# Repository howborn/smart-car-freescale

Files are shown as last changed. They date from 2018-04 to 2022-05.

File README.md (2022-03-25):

# [第九届飞思卡尔智能车](https://www.fanhaobai.com)

此为第九届飞思卡尔智能车摄像头组参赛作品，为了该作品我和团队泡了 1 年半的实验室。该作品我早已在 [智能车制作](http://www.znczz.com) 论坛开源过，现整理于 Github。

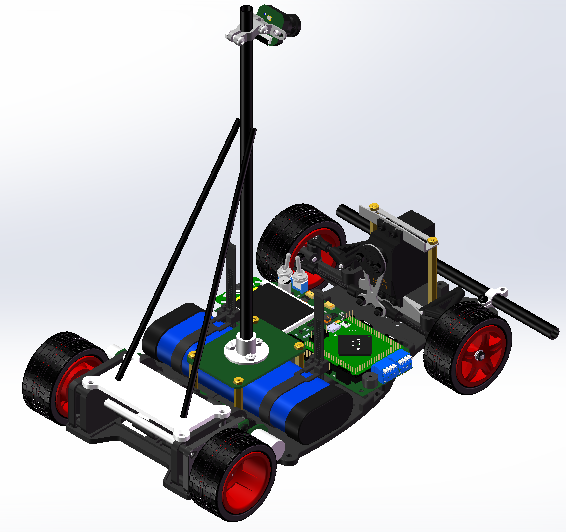
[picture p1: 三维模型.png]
预览图


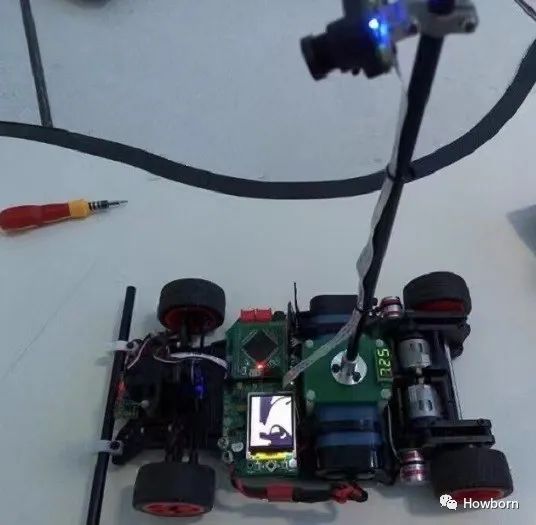
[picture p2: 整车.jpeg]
整车图


该作品系统架构为 K60 处理器 + MT9V034 CMOS 摄像头。

## [自动行驶原理](https://github.com/fan-haobai/smart-car-freescale/tree/master/4.Paper)

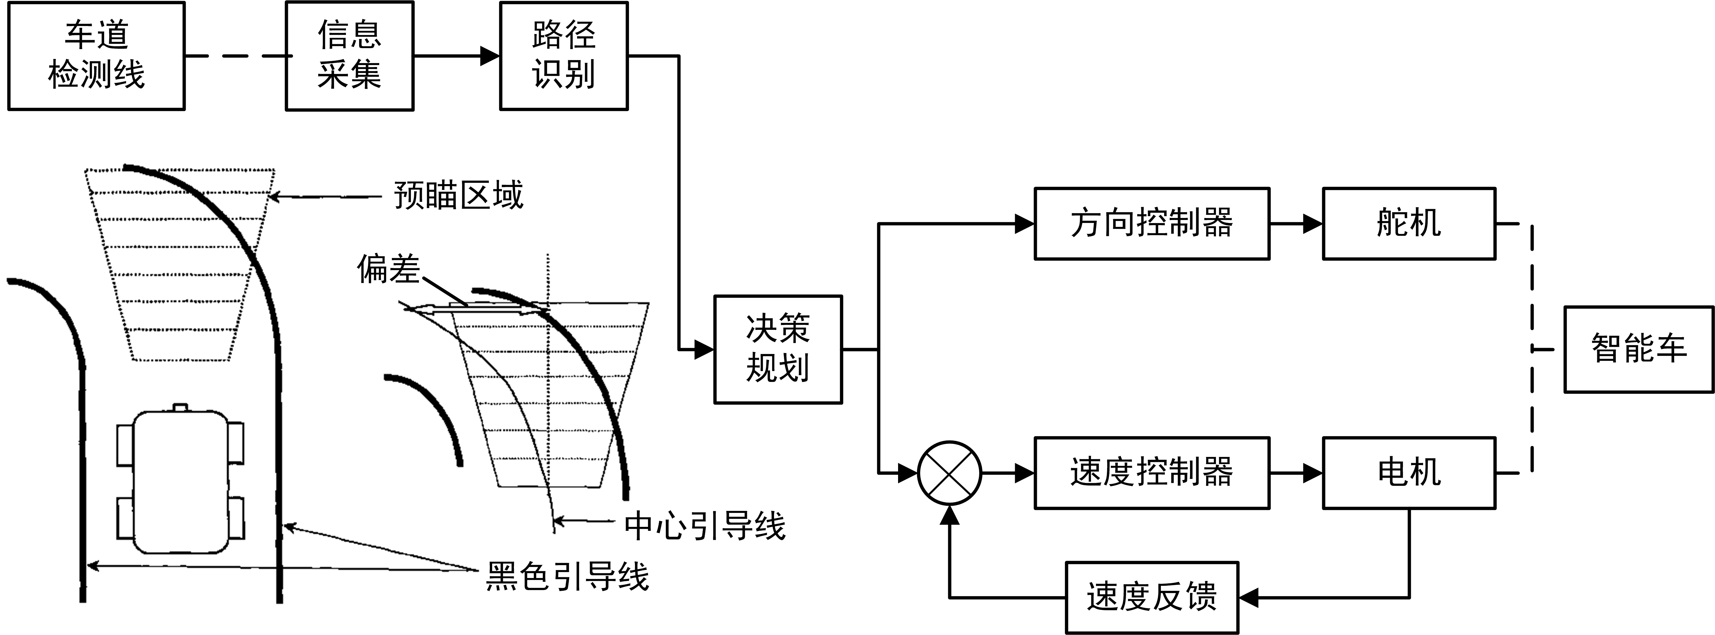
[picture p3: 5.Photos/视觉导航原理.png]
原理


整个系统通过图像识别技术感知赛道路况，进而使用 PID 算法控制智能车的速度和方向，实现智能车的自动导航功能。

## [三维建模](https://github.com/fan-haobai/smart-car-freescale/tree/master/1.3D)

使用 SolidWorks 软件对智能车进行建模分析。

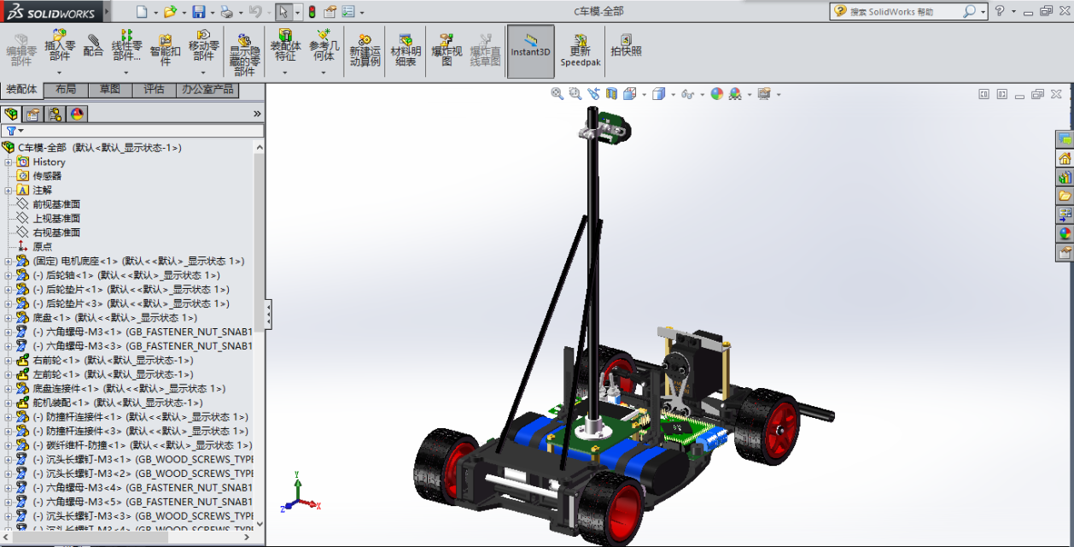
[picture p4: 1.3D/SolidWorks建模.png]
车架


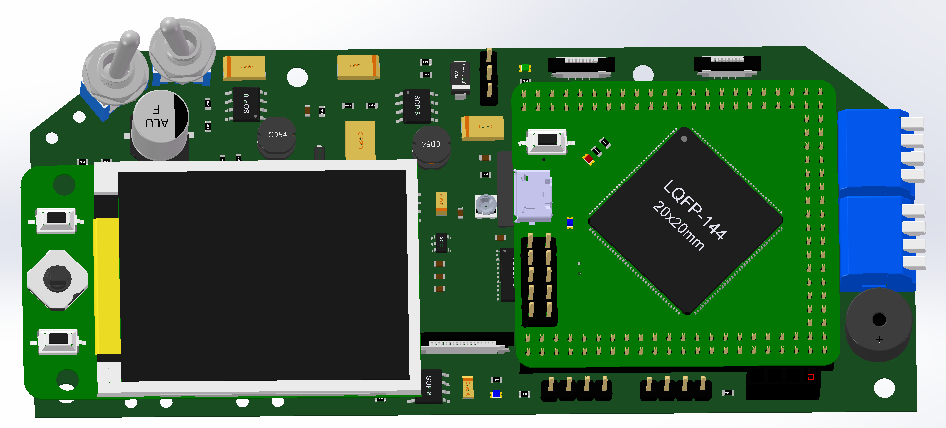
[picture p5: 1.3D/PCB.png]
PCB


## [硬件电路](https://github.com/fan-haobai/smart-car-freescale/blob/master/2.Hardware)

硬件电路主要分为4个子部分：

* [摄像头](https://github.com/fan-haobai/smart-car-freescale/blob/master/2.Hardware/摄像头.PDF)
* [K60 最小系统](https://github.com/fan-haobai/smart-car-freescale/blob/master/2.Hardware/K60最小系统.PDF)
* [可视化交互界面](https://github.com/fan-haobai/smart-car-freescale/blob/master/2.Hardware/1.8-TFT-128x160.PDF)
* [主板](https://github.com/fan-haobai/smart-car-freescale/blob/master/2.Hardware/主板__V1.0.PDF)

其中，部分电路原理图：

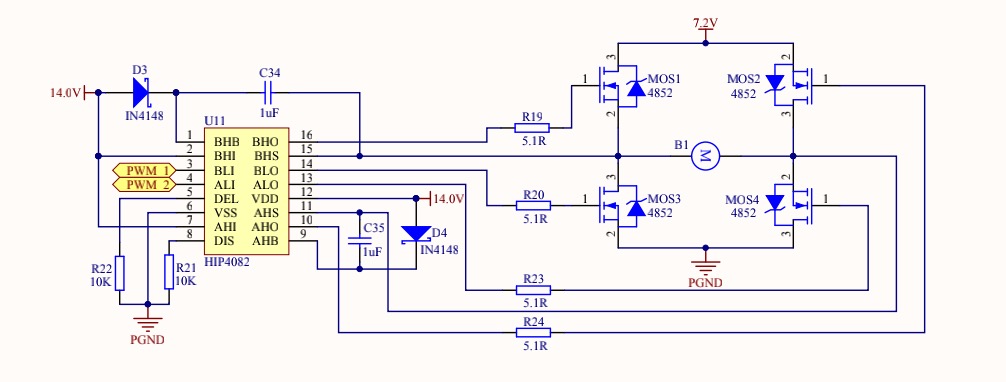
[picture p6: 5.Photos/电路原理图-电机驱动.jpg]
电机驱动


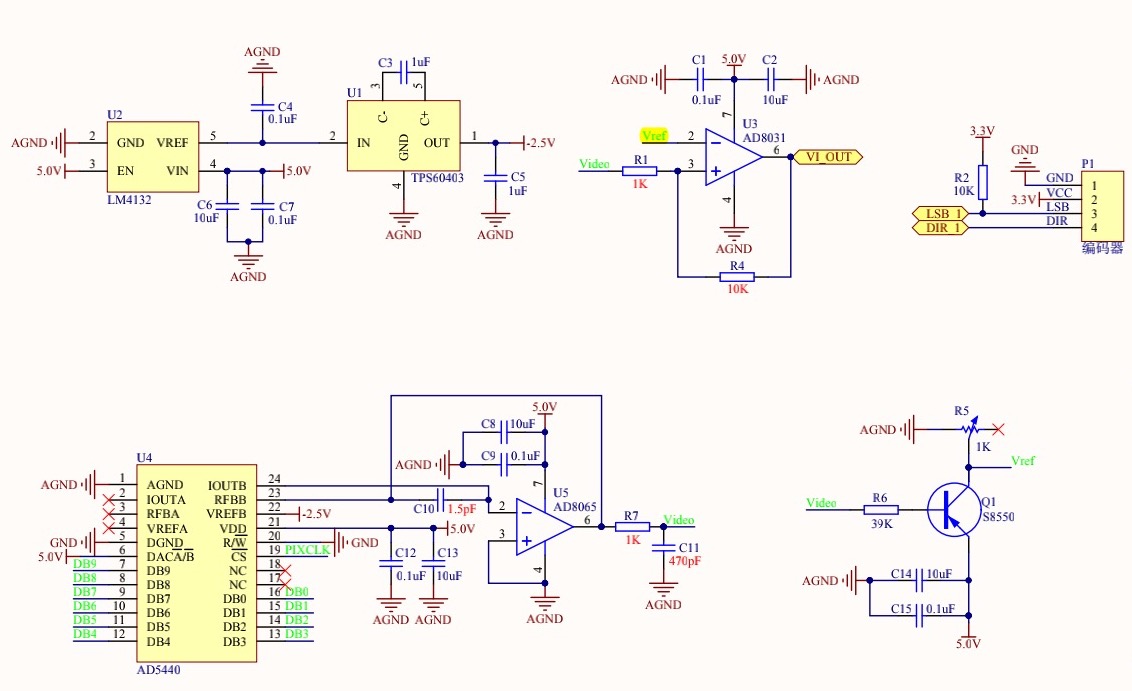
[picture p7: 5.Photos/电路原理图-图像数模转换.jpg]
图像数模转换


## [软件源码](https://github.com/fan-haobai/smart-car-freescale/blob/master/3.Software)

软件主要功能包括:

* [K60 初始化和调度](https://github.com/fan-haobai/smart-car-freescale/blob/master/3.Software/src/Init.c)
* [MT9V034 图像采集](https://github.com/fan-haobai/smart-car-freescale/blob/master/3.Software/src/MT9V034.c)
* [图像分析](https://github.com/fan-haobai/smart-car-freescale/blob/master/3.Software/src/Analyze.c)
* [Flash数据存储](https://github.com/fan-haobai/smart-car-freescale/blob/master/3.Software/src/Flash.c)
* [可视化界面（GUI）](https://github.com/fan-haobai/smart-car-freescale/blob/master/3.Software/src/Gui.c)
* [PID 自动控制](https://github.com/fan-haobai/smart-car-freescale/blob/master/3.Software/src/Control.c)

## [毕业论文](https://github.com/fan-haobai/smart-car-freescale/tree/master/4.Paper)

我的本科毕业设计就是基于该作品，并获得了《优秀毕业论文》称号。

## [相册](https://github.com/fan-haobai/smart-car-freescale/tree/master/5.Photos)

制作过程中所有的图片汇集。例如赛道识别图像：

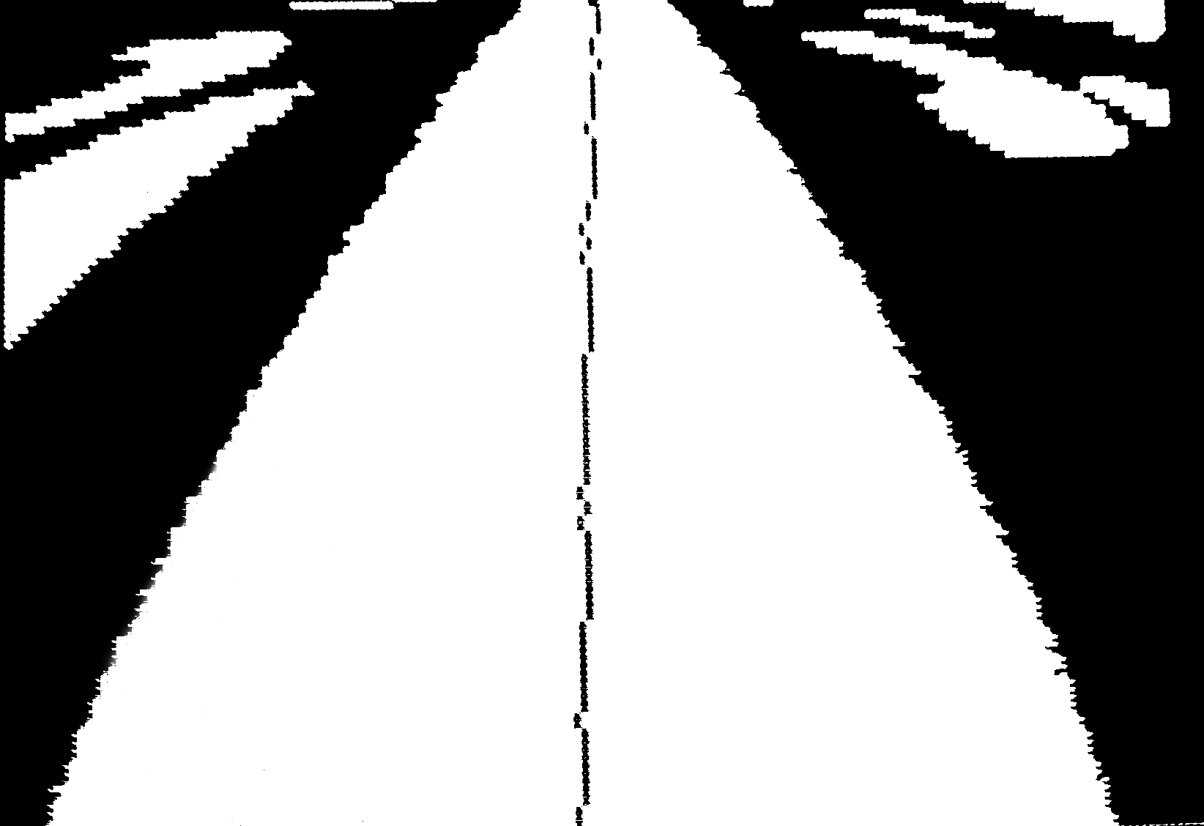
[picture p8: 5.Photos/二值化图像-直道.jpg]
二值化图像-直道


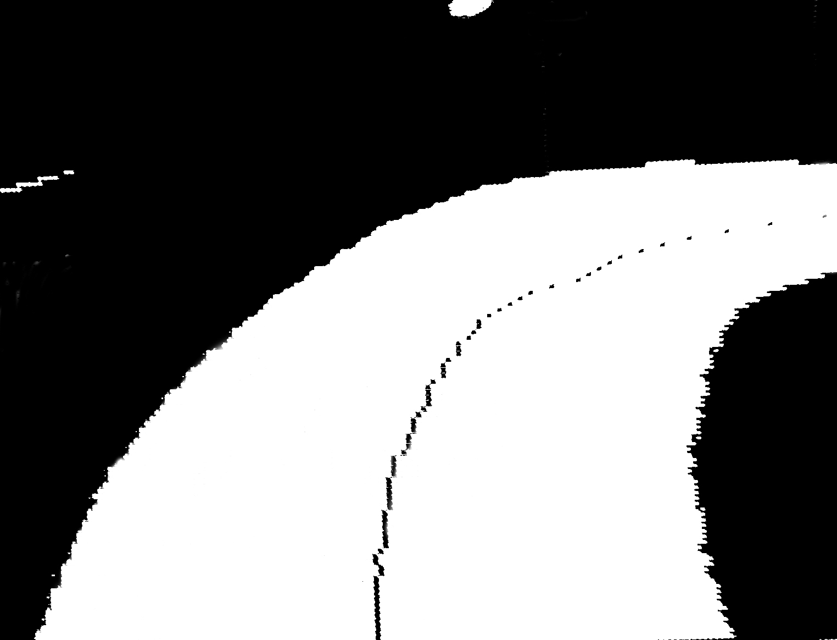
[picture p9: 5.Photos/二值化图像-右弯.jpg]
二值化图像-右弯


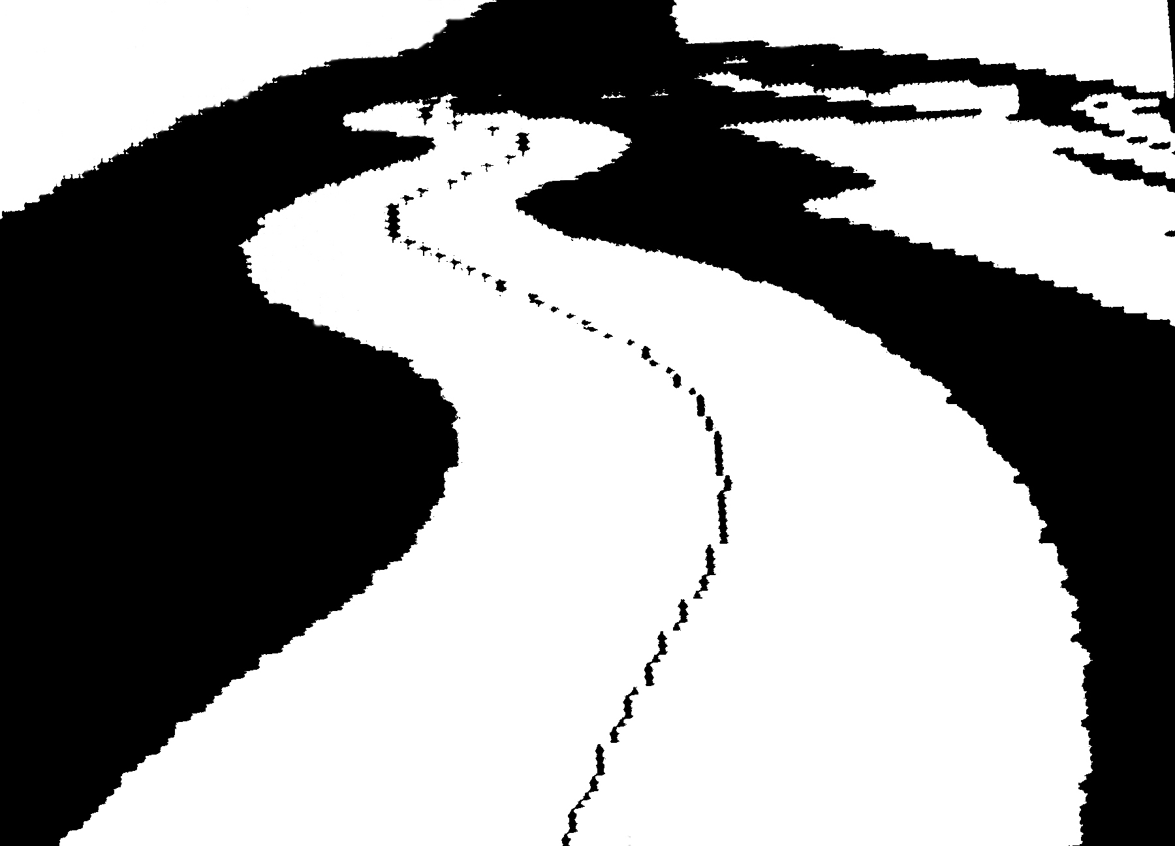
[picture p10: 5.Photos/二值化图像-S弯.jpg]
二值化图像-S弯


## 自动行驶视频

* [实验室调试视频](https://v.youku.com/v_show/id_XODE0NTg2NzY4.html)
* [校内赛](https://v.youku.com/v_show/id_XOTI0NzM1NDM2.html)
* [华北赛](https://v.youku.com/v_show/id_XODUxOTUyNjk2.html)

**最后要说的是，通过这次比赛，巩固了基础知识，也充实了大学生活。**

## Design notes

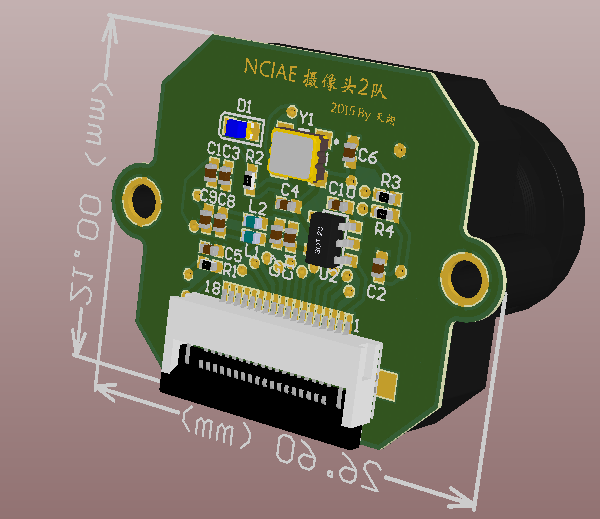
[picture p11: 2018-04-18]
2.Hardware/摄像头/3D.png

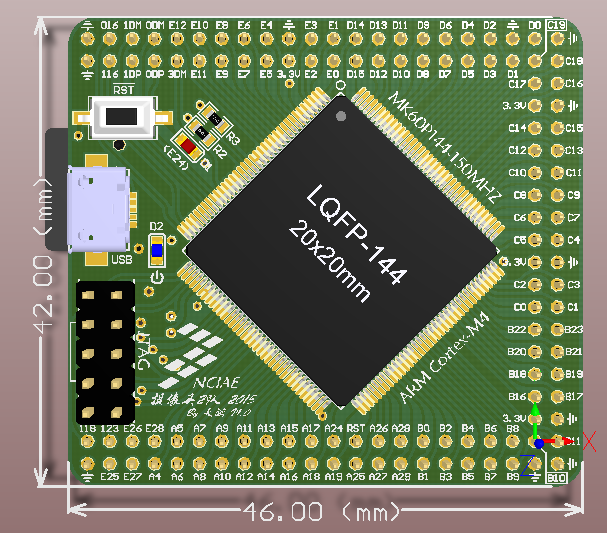
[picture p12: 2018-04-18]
2.Hardware/K60最小系统/3D.png

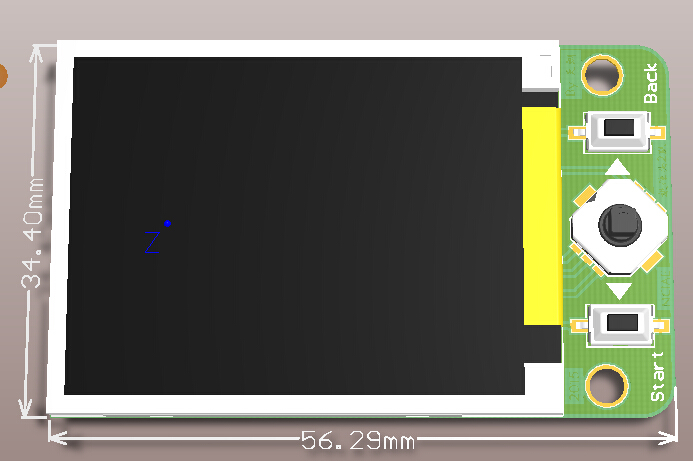
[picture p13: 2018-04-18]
2.Hardware/可视化交互界面/3D.jpg

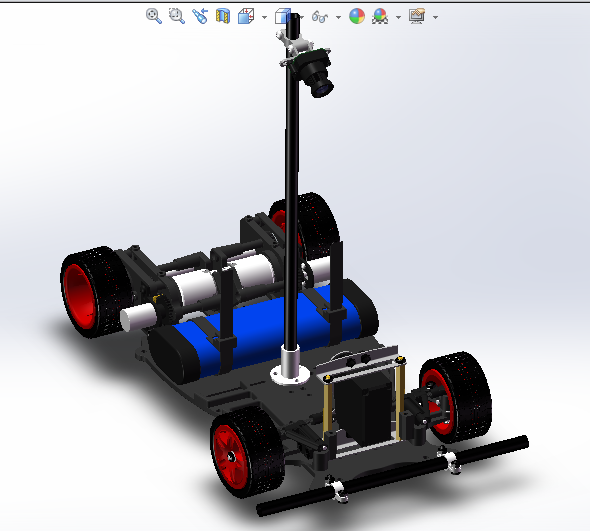
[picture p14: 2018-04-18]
1.3D/车架部分.png

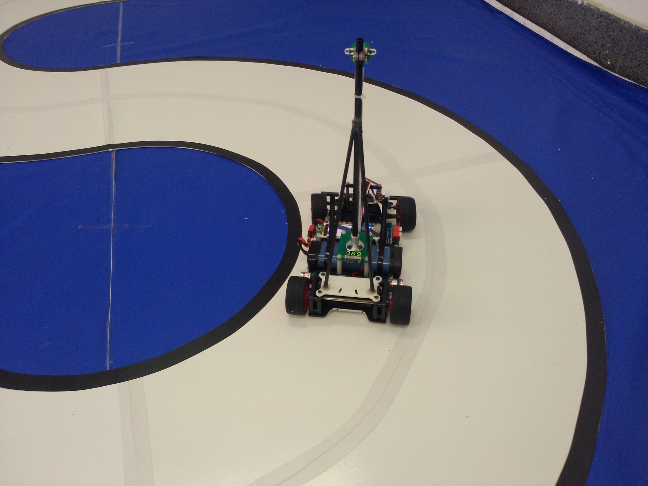
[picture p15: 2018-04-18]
5.Photos/整车-赛道.jpg

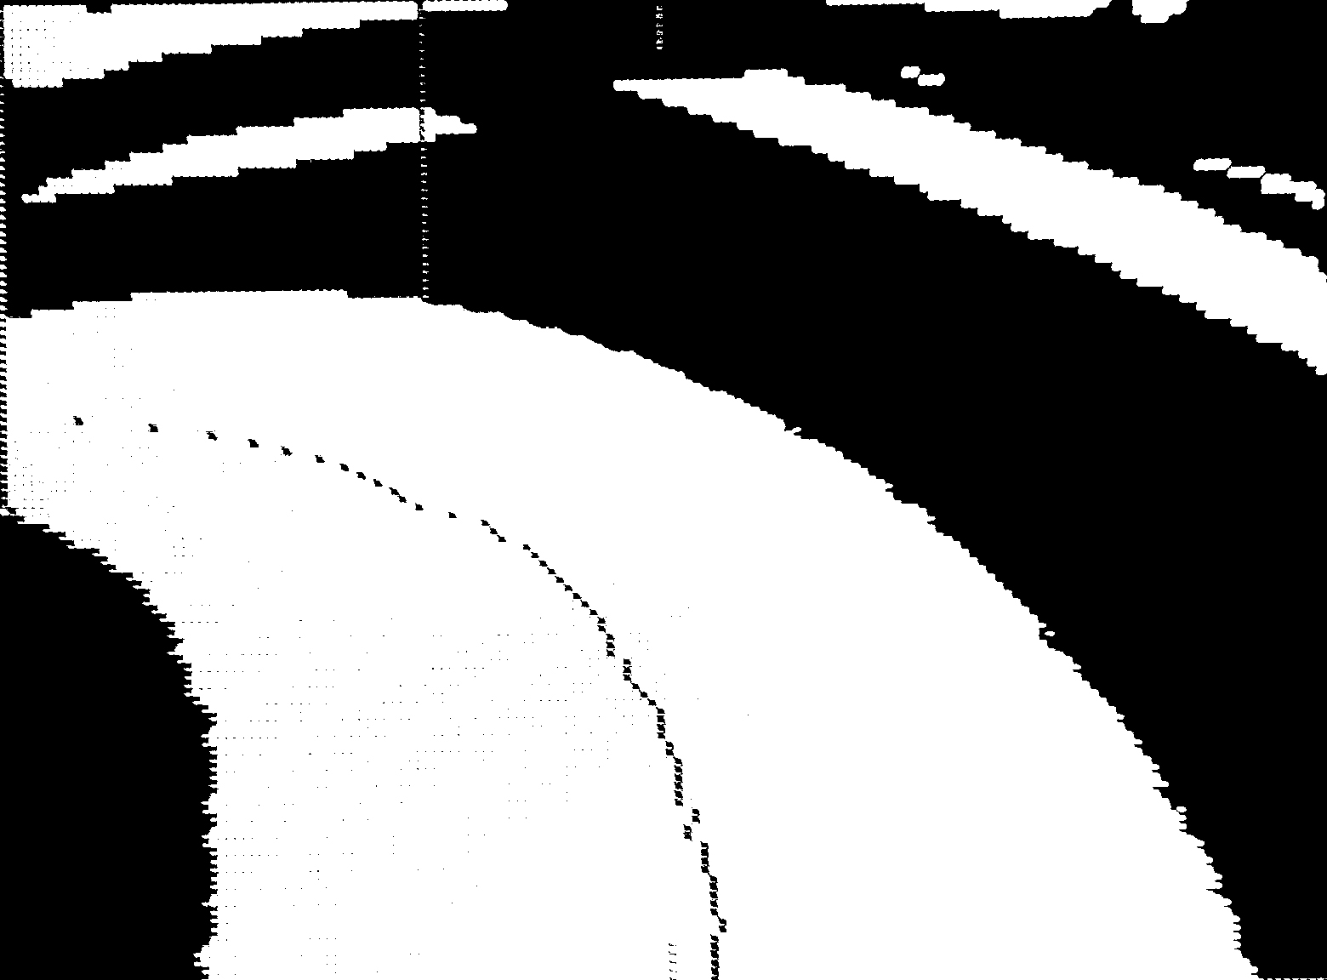
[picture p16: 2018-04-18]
5.Photos/二值化图像-左道.jpg

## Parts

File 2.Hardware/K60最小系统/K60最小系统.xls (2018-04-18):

Comment | Designator | Footprint | Quantity
0.01uF | C15 | CAP-0603 | 1
0.1uF | C1, C2, C7, C8, C9, C10, C11, C12, C13, C14, C16 | CAP-0603 | 11
0R | R8, R9 | RES-0603 | 2
100OHM@100MHZ | L1, L2 | Chip Inductor-0603_160808 | 2
10K | R1, R7 | RES-0603 | 2
10nF | C5 | CAP-0603 | 1
10uF | C17 | CASE-A_3216-18 | 1
1K | R4, R5 | RES-0603 | 2
1M | R6 | RES-0603 | 1
22pF | C3, C4 | CAP-0603 | 2
22R | R2, R3 | RES-0603 | 2
32.768k | Y1 | XTAL-XYL-SMD | 1
4.7uF | C6 | CAP-0603 | 1
4733 | D3, D4 | Diode-SMD-1206 | 2
500mA | F1 | Fuse-1206 | 1
50MHZ/3.3V | Y2 | XTAL-OSC-3225 | 1
CON-20X2 | CN1, CN2, CN3 | Pin-Header-2.00-Double-40 | 3
JTAG | CN4 | Pin-Header-2.54-Double-10 | 1
Key | RST | SW-PB-2 | 1
LED | D1 | LED-RED-0603 | 1
LED | D2 | LED-BLU-0603 | 1
ME6211-3.3 | U2 | SOT-23-5 | 1
Mini-USB-A | USB | Mini-USB(a)-SMD | 1
MK60FX512VLQ15 | U1 | LQFP-144-20x20mm | 1
SD | Micro SD | Micro-SD | 1

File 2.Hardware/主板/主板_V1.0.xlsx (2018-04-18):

Comment | Designator | Footprint | Quantity
Motor | B1, B2 | Header-5.0-SMD | 2
Battery | BT | Header-5.0-SMD | 1
0.1uF | C1, C4, C7, C9, C12, C15, C17, C23, C24, C26, C27, C28, C29, C38, C39 | CAP-0603 | 15
10uF | C2, C6, C8, C13, C14, C22, C25 | CAP-0603 | 7
1uF | C3, C5, C34, C35, C36, C37 | CAP-0603 | 6
1.5pF | C10 | CAP-0603 | 1
470pF | C11 | CAP-0603 | 1
100uF | C16, C18, C20 | CASE-C_6032-28 | 3
180pF | C19 | CAP-0603 | 1
100uF/25V | C21 | CASE-D_7343-31 | 1
10uF | C30, C31, C32 | CASE-A_3216-18 | 3
470uF | C33 | CAP-ALU-F_8.0x8.3x10.2 | 1
CON-20X2 | CN1, CN2, CN3 | Female-Header-2.00-Double-40 | 3
IN5819 | D1 | Diode-SMD-SOD-123 | 1
IN5824 | D2 | Diode-SMD-SMA | 1
IN4148 | D3, D4, D5, D6 | Diode-SMD-1206 | 4
220uH | L1 | Inductor-CD-54 | 1
33uH | L2 | Inductor-CD-54 | 1
LED | LED1 | LED-GRE-0603 | 1
LED | LED2 | LED-BLU-0603 | 1
Buzzer | LS | BUZZER_9.5*6MM | 1
4852 | MOS1, MOS2, MOS3, MOS4, MOS5, MOS6, MOS7, MOS8 | DFN-5_5X6MM | 8
编码器 | P1, P2 | Pin-Header-2.54-Single-4 | 2
摄像头 | P3 | Header-FPC-ZIF-SMD-Vertical Single-0.5-18 | 1
舵机 | P4 | Pin-Header-2.54-Single-3 | 1
红外检测 | P5 | Header-FPC-ZIF-SMD-Vertical Single-0.5-8 | 1
预留接口 | P6 | Header-FPC-ZIF-SMD-Vertical Single-0.5-8 | 1
蓝牙 | P7 | Female-Header-2.54-Single-4 | 1
1.8-TFT-128*160 | P8 | Female-Header-2.00-Double-14 | 1
S8550 | Q1 | SOT-23-3 | 1
8050 | Q2 | SOT-23-3 | 1
1K | R1, R7, R9, R14 | RES-0603 | 4
10K | R2, R3, R4, R13, R21, R22, R27, R28, R33 | RES-0603 | 9
1K | R5 | RES-Adj_PVZ3 | 1
39K | R6 | RES-0603 | 1
180R | R8 | RES-0603 | 1
6.6K | R10 | RES-0603 | 1
0.22R | R11 | RES-0603 | 1
2.7K | R12 | RES-0603 | 1
0R | R15, R18 | RES-0603 | 2
3K | R16 | RES-0603 | 1
2K | R17 | RES-0603 | 1
5.1R | R19, R20, R23, R24, R25, R26, R29, R30 | RES-0603 | 8
59K(1%) | R31 | RES-0603 | 1
20K(1%) | R32 | RES-0603 | 1
Key-3 | S1, S2 | SW-3-SMTS-102 | 2
Switch | S3, S4 | SW-Piano-DIP-4 | 2
TPS60403 | U1 | SOT-23-5 | 1
LM4132 | U2 | SOT-23-5 | 1
AD8031 | U3 | SOT-23-5 | 1
AD5440 | U4 | TSSOP-24 | 1
AD8065 | U5 | SOT-23-5 | 1
MC34063 | U6 | SOP-8 | 1
AS1015 | U7 | SOP-8 | 1
TPS7350 | U8, U9 | SOP-8 | 2
TPS7333 | U10 | SOP-8 | 1
HIP4082 | U11, U12 | SOP-16 | 2
SN74AHCT245 | U13 | TSSOP-20 | 1

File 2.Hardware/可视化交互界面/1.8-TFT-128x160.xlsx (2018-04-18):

Comment | Designator | Footprint | LibRef
0.1uF | C1 | CAP-0603 | Cap
10nF | C2 | CAP-0603 | Cap
4.7uF | C3 | CAP-0603 | Cap
CON-7X2 | CN1 | Pin-Header-2.00-Straight_SMD-14 | CON-7X2
LCD-1.8-128*160 | LCD | LCD-1.8-128*160-14P | LCD-1.8-128*160-14P
8050 | Q1 | SOT-23-3 | NPN
10K | R1 | RES-0603 | Res
10R | R2 | RES-0603 | Res
Key | S1, S2 | SW-PB-2 | Key-PB-2
Switch | S3 | SW-ALPS-5 | Switch-ALPS-5
ME6211-3.3 | U1 | SOT-23-5 | LDO

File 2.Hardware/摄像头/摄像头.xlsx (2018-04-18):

Comment | Designator | Footprint | Quantity
0.1uf | C1, C2, C3, C4, C5, C6, C8 | CAP-0402 | 7
10nf | C7, C9 | CAP-0402 | 2
1uf | C10 | CAP-0402 | 1
4.7uf | C11 | CAP-0402 | 1
Camera | Camera | Camera | 1
CON-18X1 | CN1 | HEADER-FPC-ZIF-SMD-Horizontal-0.5-18 | 1
LED | D1 | LED-BLU-0603 | 1
100OHM@100MHZ | L1, L2 | Chip Inductor-0402_100505 | 2
10K | R1 | RES-0402 | 1
1K | R2, R3, R4 | RES-0402 | 3
MT9V034 | U1 | CLCC-48-11.43X11.43 | 1
TLV70233 | U2 | SOT-23-5 | 1
26.6MHZ/3.3V | Y1 | XTAL-OSC-3225 | 1

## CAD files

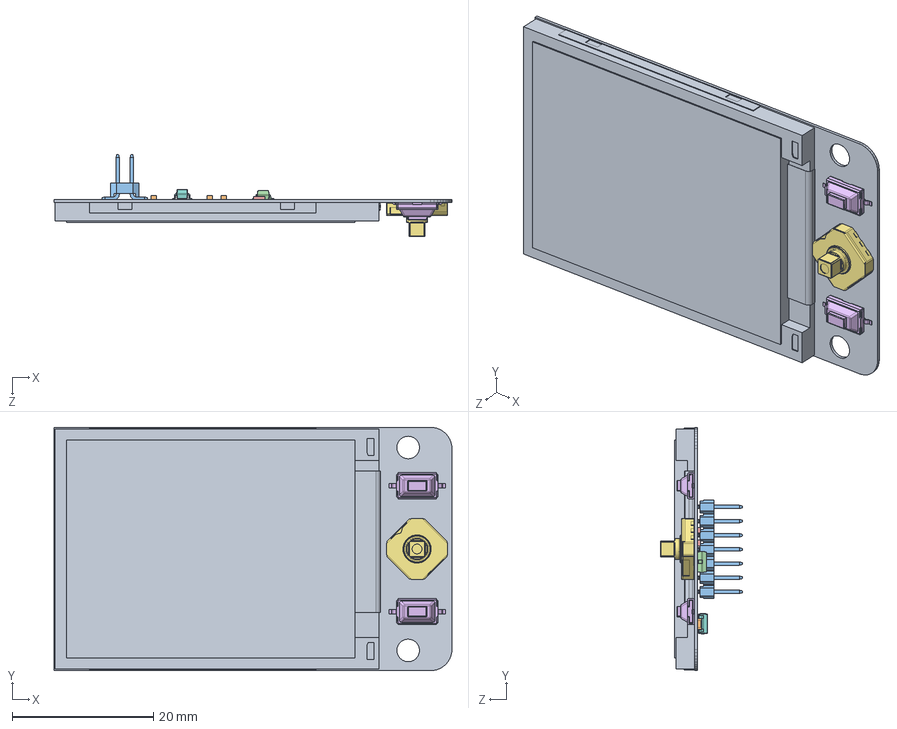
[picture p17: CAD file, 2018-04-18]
1.3D/1.8寸TFT-三维图/1.8-TFT-128x160.SLDASM
56.3 x 34.4 x 11.6 mm
Board1.8-TFT-128_160
CAP-0603 x 3
Pin-Header-2.00-Straight_SMD-14
SOT323-3
RES-0603 x 2
Switch-PB x 2
Switch-ALPS-5
SOT23-5
1.8-TFT

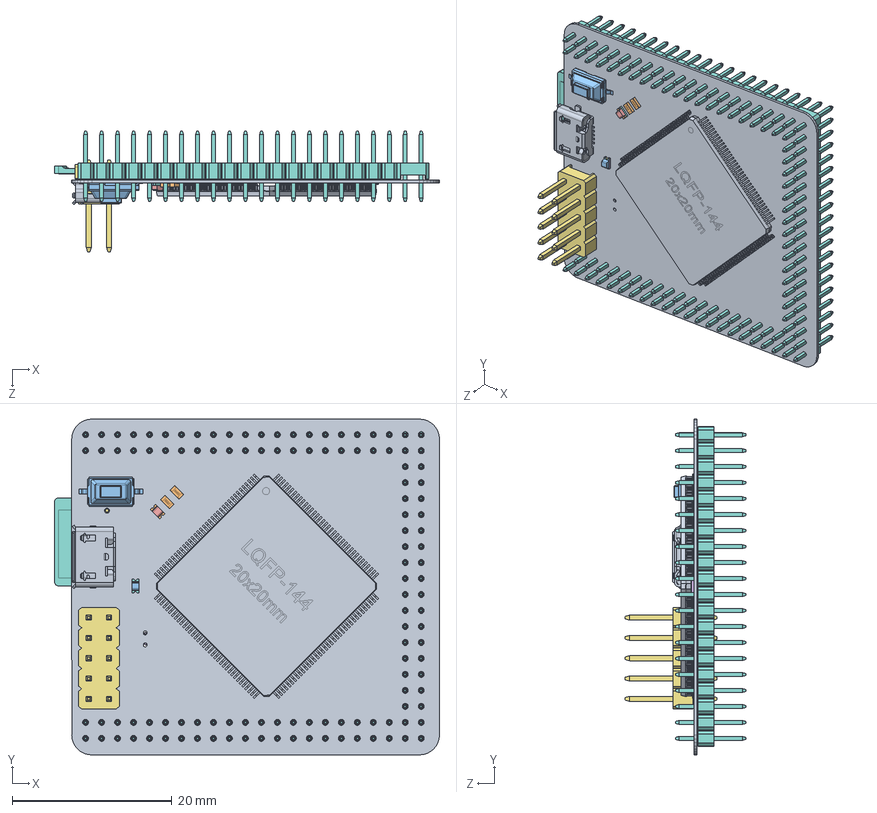
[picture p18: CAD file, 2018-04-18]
1.3D/K60最小系统.SLDASM
48.2 x 42.0 x 15.1 mm
BoardK60
User_Library-ASTX-H11_Pad
User_Library-ASTX-H11_Pad001
User_Library-ASTX-H11_Pad002
User_Library-ASTX-H11_ComponentPads
CAP-0603 x 16
CaseA_3216-18
User_Library-LTST-C190EKT_Pad
User_Library-LTST-C190EKT_Pad005
User_Library-LTST-C190EKT_Pad001
User_Library-LTST-C190EKT_Pad004
User_Library-LTST-C190EKT_Pad003
User_Library-LTST-C190EKT_Lens
User_Library-LTST-C190TBKT_Pad
User_Library-LTST-C190TBKT_Pad005
User_Library-LTST-C190TBKT_Pad001
User_Library-LTST-C190TBKT_Pad004
User_Library-LTST-C190TBKT_Pad003
User_Library-LTST-C190TBKT_Lens
Diode-SMD-1206 x 2
Fuse-1206
Chip_Inductor-_0603_160808 x 2
Micro-SD
SD-Card
Micro-USB-SMD
RES-0603 x 9
Switch-PB
SOT23-5
User_Library-R38_100mils_Fillet
零件1 x 2
Pin-Header-2.54-Double-10
Pin-Header-2.00-Double-40 x 3
LQFP-144-20x20mm

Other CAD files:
1.3D/主板-三维图/CN3主板_V1.0.sldasm
1.3D/摄像头-三维图/C1摄像头.sldasm
1.3D/最小系统-三维图/C14K60.sldasm
1.3D/摄像头-三维图/R3摄像头.sldasm
1.3D/最小系统-三维图/D1K60.sldasm
1.3D/摄像头-三维图/C3摄像头.sldasm
1.3D/1.8寸TFT-三维图/U11.8-TFT-128_160.sldasm
1.3D/主板-三维图/D2主板_V1.0.sldasm
1.3D/摄像头-三维图/C6摄像头.sldasm
1.3D/最小系统-三维图/RSTK60.sldasm
1.3D/主板-三维图/D4主板_V1.0.sldasm
1.3D/最小系统-三维图/R7K60.sldasm
1.3D/1.8寸TFT-三维图/C21.8-TFT-128_160.sldasm
1.3D/主板-三维图/CN2主板_V1.0.sldasm
1.3D/摄像头-三维图/LED-BLUE-0603.sldasm
1.3D/最小系统-三维图/C17K60.sldasm
1.3D/1.8-TFT-128x160.SLDASM
1.3D/1.8-TFT.sldprt
1.3D/1.8寸TFT-三维图/1.8-TFT.sldprt
1.3D/1.8寸TFT-三维图/Back1.8-TFT-128_160.sldasm
1.3D/1.8寸TFT-三维图/Board1.8-TFT-128_160.sldprt
1.3D/1.8寸TFT-三维图/C11.8-TFT-128_160.sldasm
1.3D/1.8寸TFT-三维图/C31.8-TFT-128_160.sldasm
1.3D/1.8寸TFT-三维图/CAP-0603.sldprt
1.3D/1.8寸TFT-三维图/CN11.8-TFT-128_160.sldasm
1.3D/1.8寸TFT-三维图/LCD1.8-TFT-128_160.sldasm
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

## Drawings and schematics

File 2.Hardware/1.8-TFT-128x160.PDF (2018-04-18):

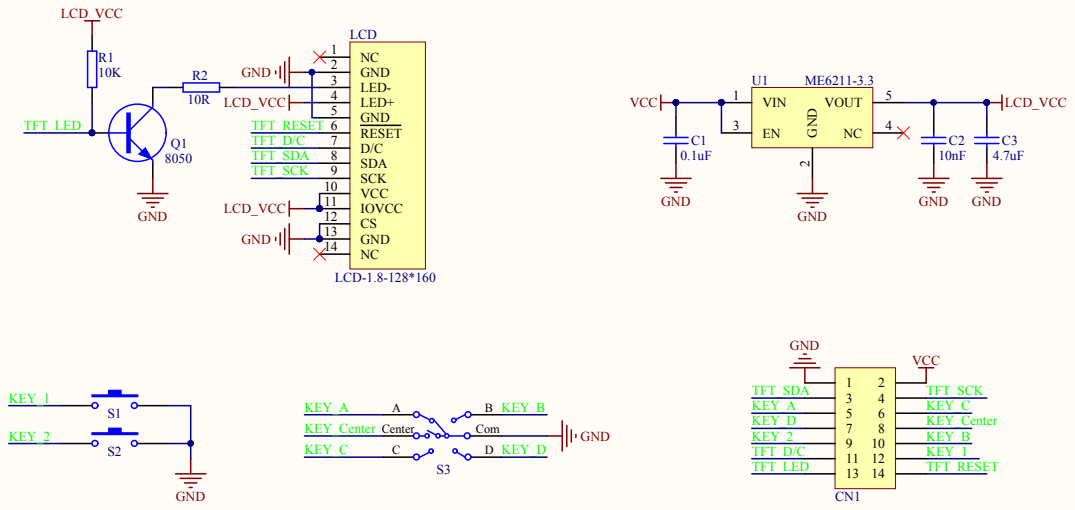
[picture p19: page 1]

Title 1.8-TFT-128x160 | Altium Limited L3, 12a Rodborough Rd Frenchs Forest NSW Australia 2086
Revision: V1.0 | Number: 1 | Designer: 樊浩柏

Date: 2015/3/10 Time: 20:09:24 | | Sheet 1 of 1

F:\Technology\工程\飞思卡尔\摄像头组\电路\1.8-TFT-128x160\1.8-TFT-128x160.SchDoc

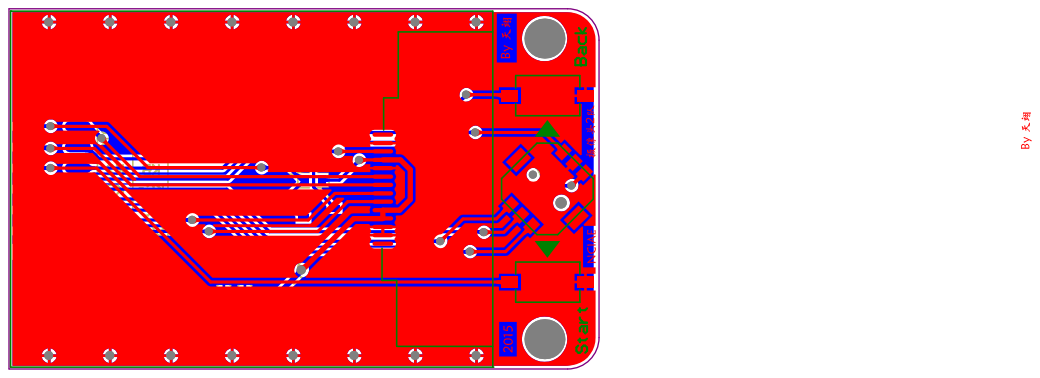
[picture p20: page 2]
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

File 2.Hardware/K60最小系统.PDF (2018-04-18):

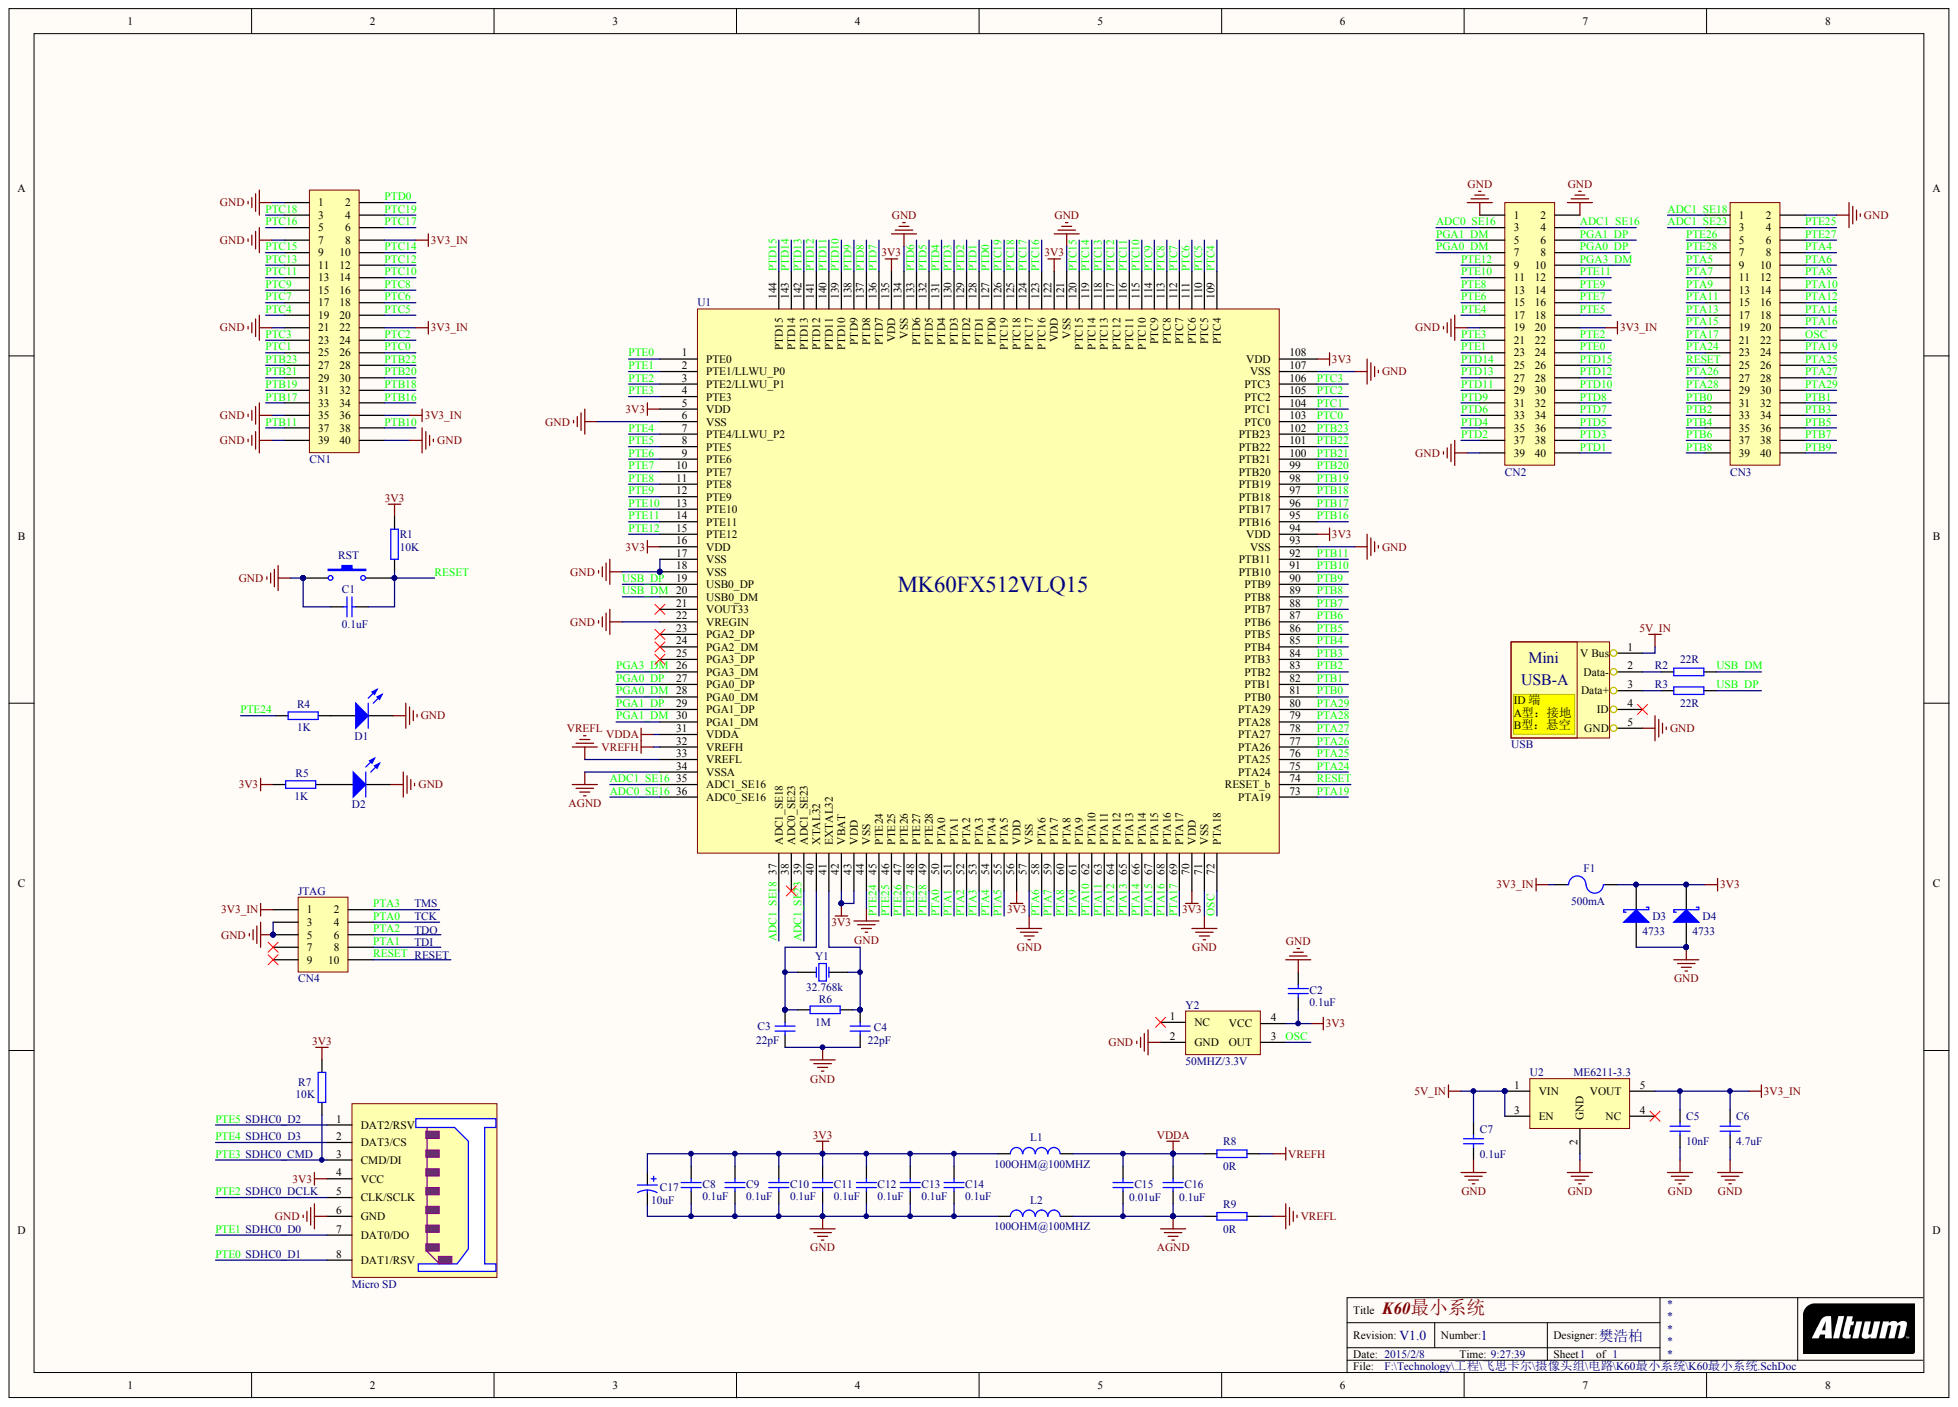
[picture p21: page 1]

PTC4 109 PTC5 110 PTC6 111 PTC7 112 PTC8 113 PTC9 114 PTC10 115 PTC11 116 PTC12 117 PTC13 118 PTC14 119 PTC15 120 VSS 121 VDD 122 PTC16 123 PTC17 124 PTC18 125 PTC19 126 PTD0 127 PTD1 128 PTD2 129 PTD3 130 PTD4 131 PTD5 132 PTD6 133 VSS 134 VDD 135 PTD7 136 PTD8 137 PTD9 138 PTD10 139 PTD11 140 PTD12 141 PTD13 142 PTD14 143 PTD15 144

Title | **** *

Revision: V1.0 | Number: | Designer:
Date: 2015/2/8 Time: 9:27:39 | | Sheet 1 of 1

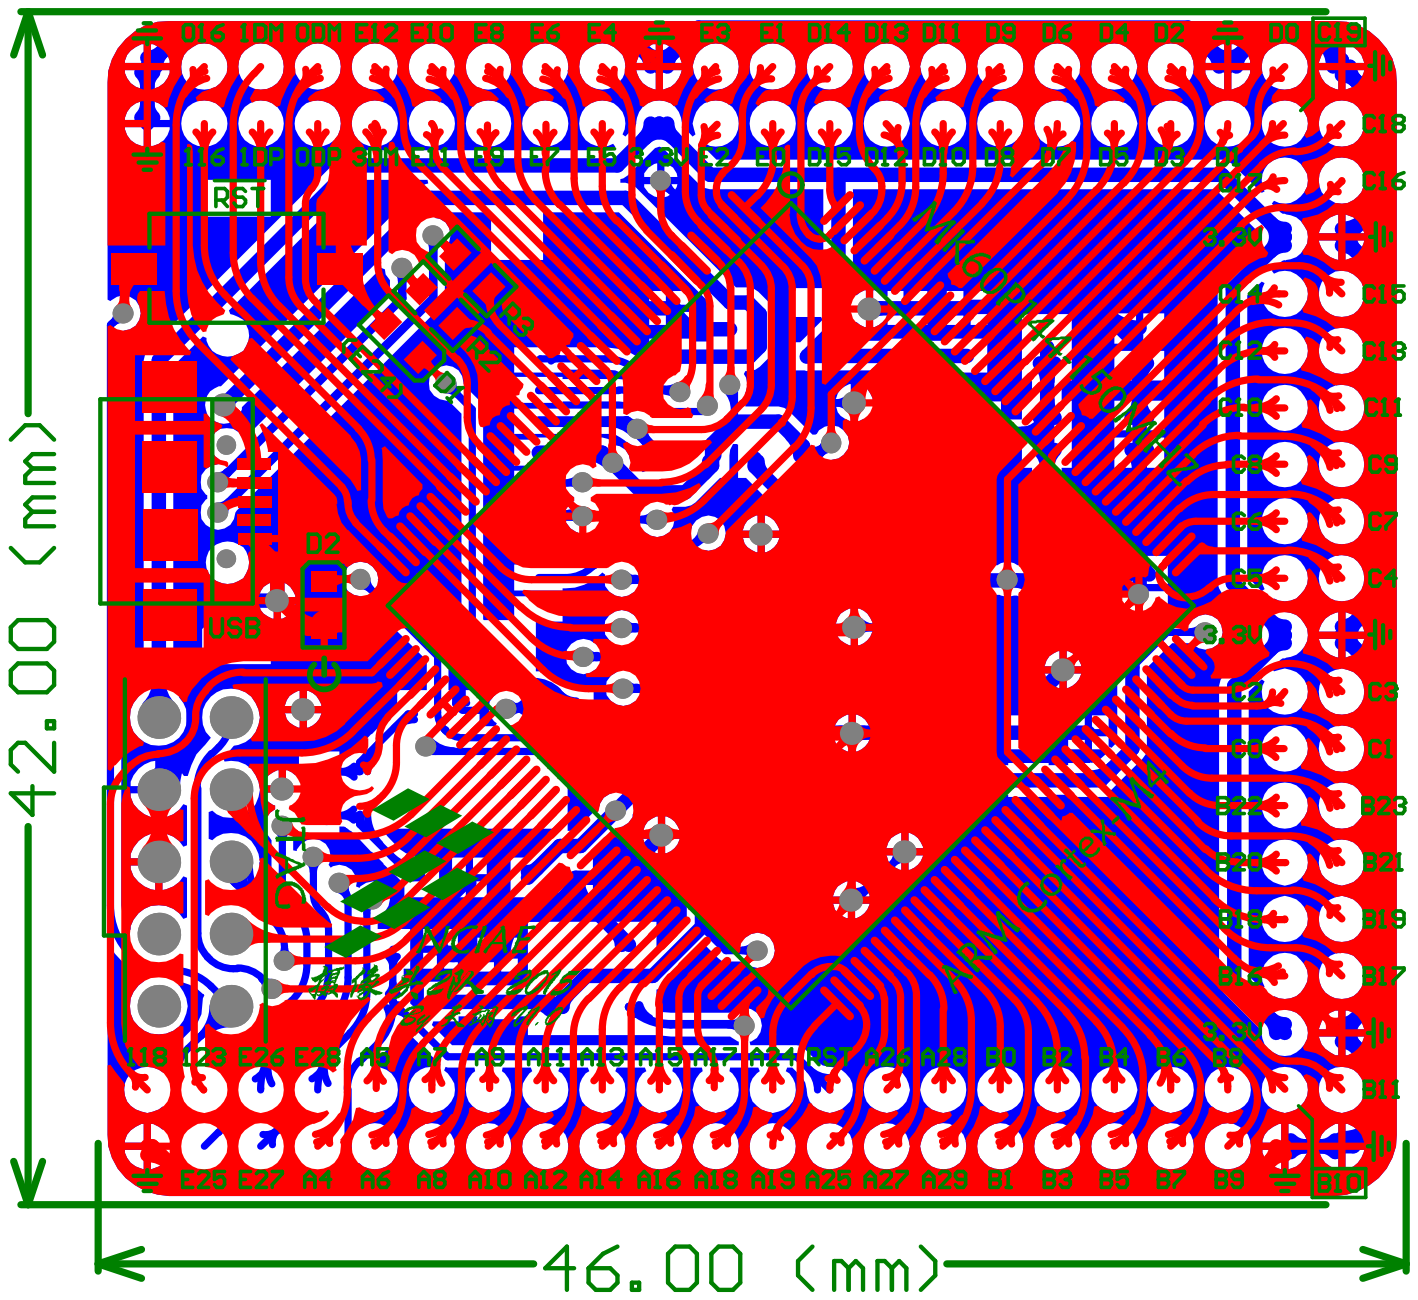
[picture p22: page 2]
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

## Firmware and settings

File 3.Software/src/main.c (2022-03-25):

/**
 * --------------Smart_Car工程-----------------
 * @file Smart_Car.c
 * @version 0.0
 * @date 2015-2-7
 *
 *
 * 版权所有:  北华航天工学院 第十届飞思卡尔  摄像头2队
 * 硬件平台:  MK60FX512
 *
 *逻辑简单说明
 *第一个薄码开关确定车子再跑的过程中是否把图片存储到SD卡中
 *然后如果第二个薄码开关拨下去说明数据的来源是SD卡中的数据，所以就屏蔽掉图像实时处理的部分
 *两部分不一样的地方只是图像数据的来源
 *实时处理部分先得到图像。然后找线，找控制的中线，方向控制，速度控制，速度和期望速度标定，然后虚拟示波器发送函数。
 *SD卡分析部分，前部分是FatFs系统的东西，是如何读取图片，也就是平常调试部分，原理就是车载屏幕的刷新时间比较短，
   所以我们一张张翻图片然后发现图片有问题的时候用按键控制发送到串口助手中用于分析，当拿到车子这部分会很快的适应的。
 *主函数分析完毕
 */
#include "common.h"
#include "global.h"
#include "control.h"
#include "interrupt.h"
#include "init.h"
#include "gui.h"
#include "analyze.h"
#include "tft.h"

//文件系统文件
uint32 size, sizetmp;
int16  res,synchronous=0;

//虚拟示波器检验
uint16 CRC_Check(uint8 *buf, uint8 CRC_CNT)
{
    uint16 CRC_temp;
    uint8 i,j;
    CRC_temp = 0xffff;
    for (i=0;i<CRC_CNT; i++){
        CRC_temp ^= buf[i];
        for (j=0;j<8;j++) {
            if (CRC_temp & 0x01)
                CRC_temp = (CRC_temp >>1 ) ^ 0xa001;
            else
                CRC_temp = CRC_temp >> 1;
        }
    }
    return(CRC_temp);
}
//虚拟示波器封装发送函数
void OutPut_Data(void)
{
  uint8 databuf[10] = {0};
  uint8 i;
  uint16 CRC16 = 0;
  for(i=0;i<4;i++)
  {
    databuf[i*2]   = (uint8)(Send_Data[i]%256);
    databuf[i*2+1] = (uint8)(Send_Data[i]/256);
  }
  CRC16 = CRC_Check(databuf,8);
  databuf[8] = CRC16%256;
  databuf[9] = CRC16/256;
  for(i=0;i<10;i++)
     LPLD_UART_PutChar(UART0,databuf[i]);
}

//主函数
void main (void)
{
  DisableInterrupts;                  //关闭全局中断
  Init();                             //系统初始化
  EnableInterrupts;                   //使能全局中断

  FIL     fdst;   //文件
  FATFS   fs;     //文件系统
  memset(buff,0,BUFF_SIZE);
  f_mount(0, &fs);                                                              //挂载文件系统
  res = f_open(&fdst, "0:/Smtcar.txt", FA_OPEN_ALWAYS | FA_WRITE | FA_READ);    //打开文件如果存在就替换，如果没有就创建，带读写打开//FA_OPEN_ALWAYS(如果存在就保持)FA_CREATE_ALWAYS
  if( res == FR_DISK_ERR)
  {
    printf( "\n没插入SD卡??\n" );
    return;
  }
  else if ( res == FR_OK )
  {
    printf( "\n文件打开成功 \r\n" );
  }
  else
  {
    printf("\n返回值异常");
    return;
  }

  while(1)
  {
    if(PTC1_I==1)     //如果第二个按键没有按下是实时采集处理程序
    {
      if(PTA6_I == 0)
      {
        LPLD_GPIO_ClearIntFlag(PORTC);
        Stop_Flag=0;
      }
      Picture_get();
      if(PTC0_I==0 && Stop_Flag == 0)
      {
        f_write(&fdst,&buff,BUFF_SIZE,&size);
        synchronous=1;
      }
      Find_Line(Image);
      Get_Center_Line();
      Direction_Control();
      Speed_Control();
      Send_Data[0] = Get_L_Speed;
      Send_Data[1] = Set_L_Speed;
      Send_Data[2] = Get_R_Speed;
      Send_Data[3] = Set_R_Speed;
      OutPut_Data();
      if(Stop_Flag == 1)
      {
         GUI_Menu(Image);
         if(synchronous==1)
         {
           f_sync(&fdst);                                              //刚才写入了数据，实际上数据并没真正完成写入，需要调用此函数同步或者关闭文件，才会真正写入
           synchronous=2;
         }
      }
      LPLD_GPIO_Toggle_b(PTE,24);
    }
    else       //如果第二个按键按下则处理的是SD卡中的程序
    {
      size = f_size(&fdst);                                       //获取文件的大小
      frame=size/(BUFF_SIZE);                                     //根据文件大小和每帧数据大小确定出共有多少帧
      f_lseek(&fdst, (Which_pic*BUFF_SIZE));                      //移动文件指针
      f_read (&fdst,buff,(BUFF_SIZE), &sizetmp);                  //读取

      for(uint8 jj=0;jj<V;jj++)
        for(uint8 l=0;l<H;l++)
          Image_show[jj][l]=buff[jj*H+l];
      if(printf_flag==0)
        printf("开始分析第 %d帧图片\r\n",Which_pic);
      Find_Line(Image_show);
      printf_flag=1;
      Get_Center_Line();
      GUI_Menu(Image_show);
      LPLD_GPIO_Toggle_b(PTE,24);
    }
  }
}

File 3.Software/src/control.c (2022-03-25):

/**
 * --------------Smart_Car工程-----------------
 * @file Control.c
 * @version 0.0
 * @date 2015-2-7
 *
 *
 * 版权所有:  北华航天工学院 第十届飞思卡尔  摄像头2队
 * 硬件平台:  MK60FX512
 * 
 */
#include "common.h"
#include "global.h"

int16 D_Error = 0;
int16 D_Last_Error = 0;

int16 S_L_Error = 0;
int16 S_L_DError = 0;
int16 S_L_DDError = 0;
int16 S_L_Pre_Error = 0;
int16 S_L_Pre_DError = 0;

int16 S_R_Error = 0;
int16 S_R_DError = 0;
int16 S_R_DDError = 0;
int16 S_R_Pre_Error = 0;
int16 S_R_Pre_DError = 0;

int8  S_PWM_Dead = 4;
int8  S_PID_Bang = 50;                                               //PID和bangbang控制切换阈值
int16 H_Speed;
int16 L_Speed;

int16 S_PWM_Max = 7000;
int16 S_PWM_Min = -7000;

uint8 Turn_Flag = 1;

float32 P1 = 0.009569,P2 = 2.962,P3 = 1000.0,Speed_Ratio = 1.0;    //前面三个系数放大了1000倍
/*-----------------------------------------------------------------------
* Get_Speed: 获取当前速度
*
* 输入：无
*
* 输出：无
-----------------------------------------------------------------------*/
void Get_Speed()
{
  Get_L_Speed = -(LPLD_FTM_GetCounter(FTM1));         //获取左轮速度(脉冲个数)
  Get_R_Speed = LPLD_FTM_GetCounter(FTM2);           //获取右轮速度
  LPLD_FTM_ClearCounter(FTM1);                       //清空计数器
  LPLD_FTM_ClearCounter(FTM2); 
} 

/*-----------------------------------------------------------------------
* Set_Speed: 设定当前速度
*
* 输入：无
*
* 输出：无
-----------------------------------------------------------------------*/
void Set_Speed()
{
  //速度策略
  if(Track_Type == 1)                               //直道
  {
    H_Speed = Straight_High_Speed;
    L_Speed = Straight_Low_Speed;
  }
  else if(Track_Type == 2)                         //直道入弯
  {
    H_Speed = S_C_High_Speed;
    L_Speed = S_C_Low_Speed;
  }
  else if(Track_Type == 3)                        //弯道
  {
    H_Speed = Curve_High_Speed;
    L_Speed = Curve_Low_Speed;
  }
  Speed = (int32)(H_Speed-(H_Speed-L_Speed)*(D_Error*D_Error)/8836.0);   //设定整车速度
  //计算左右轮设定速度
  if(Turn_Flag == 1)                                 //左转
  {
     Set_R_Speed = Speed;
     Set_L_Speed = (int32)(Set_R_Speed * (1.0/Speed_Ratio));
  }
  else                                              //右转
  {
     Set_L_Speed = Speed;
     Set_R_Speed = (int32)(Set_L_Speed * (1.0/Speed_Ratio));
  }
}

/*-----------------------------------------------------------------------
* BangBangBack: 棒棒刹车
*
* 输入：无
*
* 输出：无
-----------------------------------------------------------------------*/
void Speed_L_Back(void) 
{
  S_L_PWM =-8000; 
}

/*-----------------------------------------------------------------------
* BangBangGo: 棒棒启动
*
* 输入：无
*
* 输出：无
-----------------------------------------------------------------------*/
void Speed_L_Go(void) 
{
  S_L_PWM =8000; 
}
/*-----------------------------------------------------------------------
* BangBangBack: 棒棒刹车
*
* 输入：无
*
* 输出：无
-----------------------------------------------------------------------*/
void Speed_R_Back(void) 
{
  S_R_PWM =-8000;
}

/*-----------------------------------------------------------------------
* BangBangGo: 棒棒启动
*
* 输入：无
*
* 输出：无
-----------------------------------------------------------------------*/
void Speed_R_Go(void) 
{
  S_R_PWM =8000;
}

/*-----------------------------------------------------------------------
* Speed_L_Control: 左轮速度控制
*
* 输入：无
*
* 输出：无
-----------------------------------------------------------------------*/
static void Speed_L_Control()
{
  int32 pwm_p,pwm_i,pwm_d,s_pwm;
  
  S_L_Error = Set_L_Speed - Get_L_Speed;                          //e(k)
  S_L_DError = S_L_Error - S_L_Pre_Error;                         //e(k)-e(k-1)
  S_L_DDError = S_L_DError - S_L_Pre_DError;                      //e(k)-e(k-1)-(e(k-1)-e(k-2))
  S_L_Pre_Error = S_L_Error;                                      //挪动数据
  S_L_Pre_DError = S_L_DError;  
 
  if(S_L_Error > S_PID_Bang)           Speed_L_Go();               //BangBang
  else if(S_L_Error < -S_PID_Bang)    Speed_L_Back();             //BangBang
  else                                                            //PID              
  {
    if((S_L_Error < S_PWM_Dead) && (S_L_Error > -S_PWM_Dead))     //设置调节死区
      s_pwm = 0;
    else
    {
      if(Get_L_Speed<(0.2*Set_L_Speed)) 
        pwm_i = 0;                                              //积分分离防止震荡
      else
        pwm_i = S_L_Ki * S_L_Error;                            //积分项
      
      pwm_p = S_L_Kp * S_L_DError;                             //比例项
      pwm_d = S_L_Kd * S_L_DDError;                            //微分项
      s_pwm = (int32)(pwm_p + pwm_i + pwm_d);
    }
    S_L_PWM += s_pwm;
    
    if(S_L_PWM >= S_PWM_Max)            S_L_PWM = S_PWM_Max;         //限幅
    else if(S_L_PWM <= S_PWM_Min)      S_L_PWM = S_PWM_Min;
  }
}
/*-----------------------------------------------------------------------
* Speed_R_Control: 右轮速度控制
*
* 输入：无
*
* 输出：无
-----------------------------------------------------------------------*/
static void Speed_R_Control()
{
  int32 pwm_p,pwm_i,pwm_d,s_pwm;
  
  S_R_Error = Set_R_Speed - Get_R_Speed;                          //e(k)
  S_R_DError = S_R_Error - S_R_Pre_Error;                         //e(k)-e(k-1)
  S_R_DDError = S_R_DError - S_R_Pre_DError;                      //e(k)-e(k-1)-(e(k-1)-e(k-2))
  S_R_Pre_Error = S_R_Error;                                      //挪动数据
  S_R_Pre_DError = S_R_DError;  
  
  if(S_R_Error > S_PID_Bang)           Speed_R_Go();              //BangBang
  else if(S_R_Error < -S_PID_Bang)    Speed_R_Back();            //BangBang
  else                                                           //PID 
  {
    if((S_R_Error < S_PWM_Dead) && (S_R_Error > -S_PWM_Dead))     //设置调节死区
      s_pwm = 0;              
    else
    {
      if(Get_R_Speed<(0.2*Set_R_Speed)) 
        pwm_i = 0;                                             //积分分离防止震荡
      else
        pwm_i = S_R_Ki * S_R_Error;                            //积分项
      pwm_p = S_R_Kp * S_R_DError;                             //比例项
      
      pwm_d = S_R_Kd * S_R_DDError;                            //微分项
      s_pwm = (int32)(pwm_p + pwm_i + pwm_d);
    }
    S_R_PWM += s_pwm;
    
    if(S_R_PWM >= S_PWM_Max)            S_R_PWM = S_PWM_Max;      //限幅
    else if(S_R_PWM <= S_PWM_Min)      S_R_PWM = S_PWM_Min;
   }
}

/*-----------------------------------------------------------------------
* Stop_car: 刹车
*
* 输入：无
*
* 输出：无
-----------------------------------------------------------------------*/
void Stop_car()
{
  int16 speed;
  speed=(Get_R_Speed+Get_L_Speed)/2;
  if(speed > 20)
  {
    Speed_R_Back();
    Speed_L_Back();
  }
  else
  {
    S_L_PWM =0; 
    S_R_PWM =0;
  }
}
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

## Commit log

2018-04-18 初次提交
    [1.8-TFT-128x160.PcbDoc, 1.8-TFT-128x160.SLDASM, 1.8-TFT-128x160.SchDoc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]
2018-04-18 预览图修改
2018-04-18 增加pcb预览图
2022-03-25 feat:remove something
    [1.8-TFT-128x160.PcbDoc, 1.8-TFT-128x160.SLDASM, 1.8-TFT-128x160.SchDoc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]
